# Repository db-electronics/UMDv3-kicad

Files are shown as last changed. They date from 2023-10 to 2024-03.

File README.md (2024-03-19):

# UMDv3
The [Universal Mega Dumper v3](https://github.com/db-electronics/UMDv3) project is an open-source solution for cartridge dumping and writing. 

This PCB includes a very performant MCU, STM32F407VET6, which is connected to a generalized databus consisting of 24 address bits and 16 data lines. Along with a dozen or so control signals, it should be sufficient to interface with most cartridge types. Each cartridge type requires a separate PCB for interface, please refer to the main project repository for a list of currently available cartridge apdapters.

# Project
Please refer to the [UMDv3 Firmware Project Repository](https://github.com/db-electronics/UMDv3) for UMDv3 documentation and instructions; this is the project's central repository and where the wiki is hosted.

# Dependencies
## Parts Libraries
All components in this PCB depend on [my KiCad libraries](https://github.com/db-electronics/kicadlib) which are available here on github. I don't use any pre-existing libraries - *fight me*.

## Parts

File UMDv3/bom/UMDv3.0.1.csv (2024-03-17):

Item | Qty | Reference(s) | Value | Description | Digikey
1 | 14 | C101, C104, C108, C114, C115, C116, C117, C118, C119, C120, C121, C122, C123, C124 | 0.1uF/50V | CAP CER 0.1UF 50V X7R 0603 | 1276-CL10B104KB8NNNLCT-ND
2 | 2 | C102, C103 | 47uF/10V | CAP TANT 47UF 20% 10V 1206 | 478-9009-1-ND
3 | 2 | C105, C106 | 2.2uF/16V | CAP CER 2.2UF 16V X7R 0805 | 399-C0805C225K4RAL7800CT-ND
4 | 4 | C107, C125, C126, C127 | 10uF/25V | CAP CER 10UF 25V X5R 0805 | 1276-2891-1-ND
5 | 2 | C109, C110 | 22pF/50V | CAP CER 22PF 50V C0G/NP0 0603 | 399-6865-1-ND
6 | 3 | C111, C112, C113 | 1uF/16V | CAP CER 1UF 16V X7R 0805 | 399-C0805C105M4RAC7800CT-ND
7 | 1 | CON101 | USB-B1HSB6 | CONN USB TYPE B R/A BLACK | ED2983-ND
8 | 1 | CON104 | JTAG-2X10-HDR | JTAG 2X10 HEADER | ED10524-ND
9 | 1 | CON105 | 101-00405-75 | CONN SD CARD PUSH-PUSH R/A SMD | 101-00405-75-ND
10 | 1 | CON106 | UMDv3-CONN | CONN RCPT 32POS 0.1 GOLD PCB | SAM1211-32-ND
11 | 1 | CON107 | HDR1X3 | CONN HEADER 3 POS 2.54 | 732-5316-ND
12 | 2 | D101, D102 | 151031VS06000 | LED GREEN DIFFUSED 3MM ROUND T/H | 732-5008-ND
13 | 1 | D103 | 151033RS03000 | LED RED CLEAR 3MM ROUND T/H | 732-5013-ND
14 | 1 | FB101 | 1K@100MHz | FERRITE BEAD 1 KOHM 0805 1LN | 732-6704-1-ND
19 | 6 | MEC101, MEC102, MEC103, MEC104, MEC105, MEC106 | NSP-4-6-01 | MACHINE SCREW PAN PHILLIPS 4-40 | RPC3132-ND
20 | 1 | R101 | 1.5k | RES SMD 1.5K OHM 1% 1/10W 0603 | 311-1.5KLDCT-ND
21 | 2 | R102, R103 | 2.2k | RES SMD 2.2K OHM 1% 1/10W 0603 | 311-2.2KLDCT-ND
22 | 4 | R104, R105, R106, R108 | 470 | RES SMD 470 OHM 1% 1/10W 0603 | 311-470LDCT-ND
23 | 2 | R107, R111 | 10k | RES SMD 10K OHM 1% 1/10W 0603 | 311-10KLDCT-ND
24 | 1 | R109 | 715 | RES SMD 715 OHM 1% 1/10W 0603 | 311-715HRCT-ND
25 | 8 | SW101, SW102, SW103, SW104, SW105, SW106, SW107, SW108 | PTS645SM43SMTR92_LFS | SWITCH TACTILE SPST-NO 0.05A 12V | CKN9112CT-ND
26 | 2 | TP101, TP102 | TP_2.25x3_ROUNDED | 0.05" x 0.06" SMT Test Point
27 | 1 | U101 | MCP23008T-E_SS | IC I/O EXPANDER 8BIT I2C 20-SSOP | MCP23008T-E/SSCT-ND
28 | 1 | U102 | AZ1117CH-3.3TRG1 | IC REG LINEAR 3.3V 800MA SOT223 | AZ1117CH-3.3TRG1DICT-ND
29 | 1 | U103 | STM32F407VET6TR | IC MCU 32BIT 512KB FLASH 100LQFP | 497-19657-1-ND
30 | 1 | U104 | SSD1306-0.96-OLED-I2C | 0.96" I2C IIC 128X64 OLED Display Module Arduino Blue Color SSD1306
31 | 1 | X101 | ABLS-8.000MHZ-B4-T | CRYSTAL 8.0000MHZ 18PF SMD | 535-10212-1-ND

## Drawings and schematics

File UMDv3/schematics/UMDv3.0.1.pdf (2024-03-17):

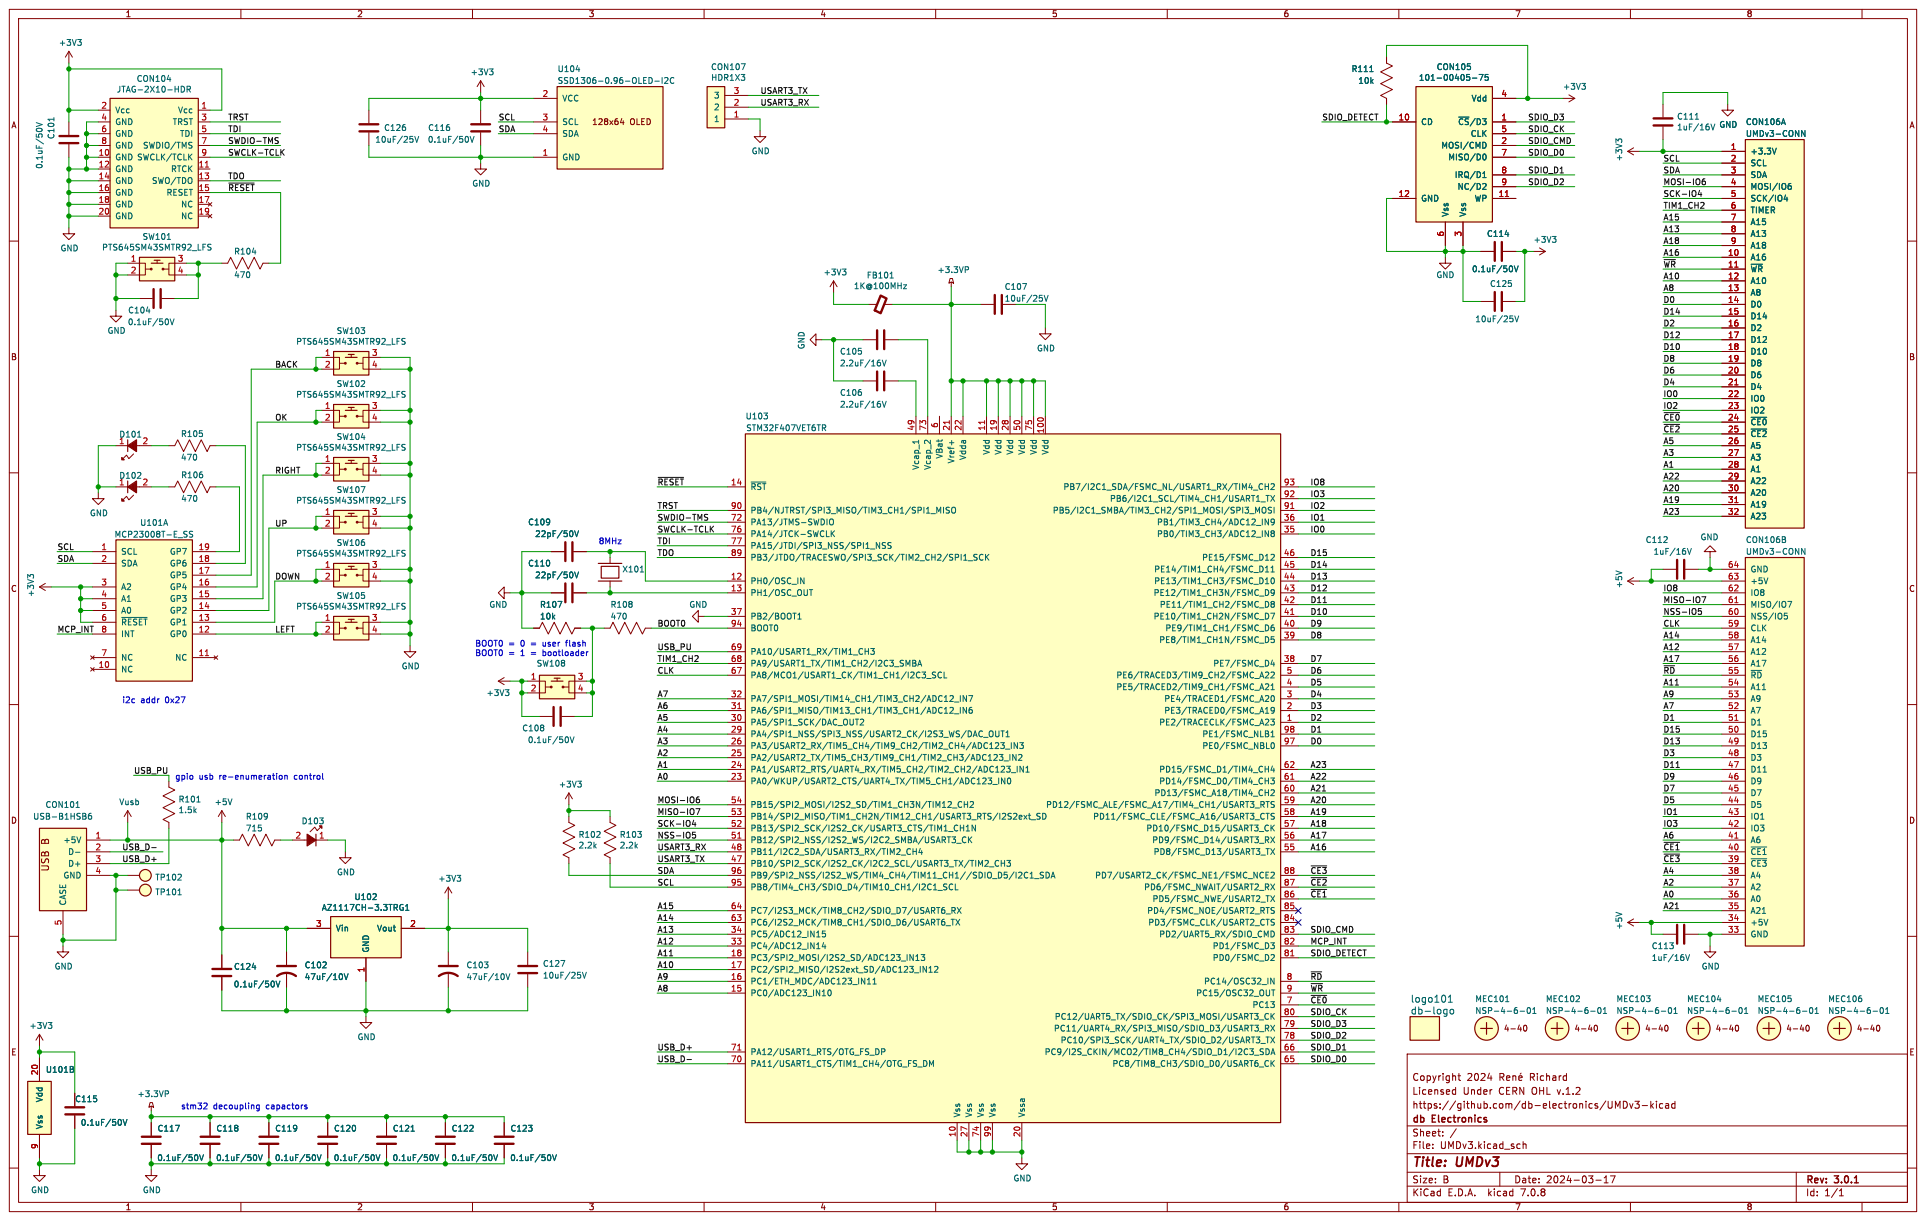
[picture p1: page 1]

A15 A13 TIM1_CH2 A10 ~{WR} A16 A18 A7A9A17 A11 ~{RD} A12 NSS-IO5 A14 CLK D15 D13 D1 SCL SDA

https://github.com/db-electronics/UMDv3-kicad

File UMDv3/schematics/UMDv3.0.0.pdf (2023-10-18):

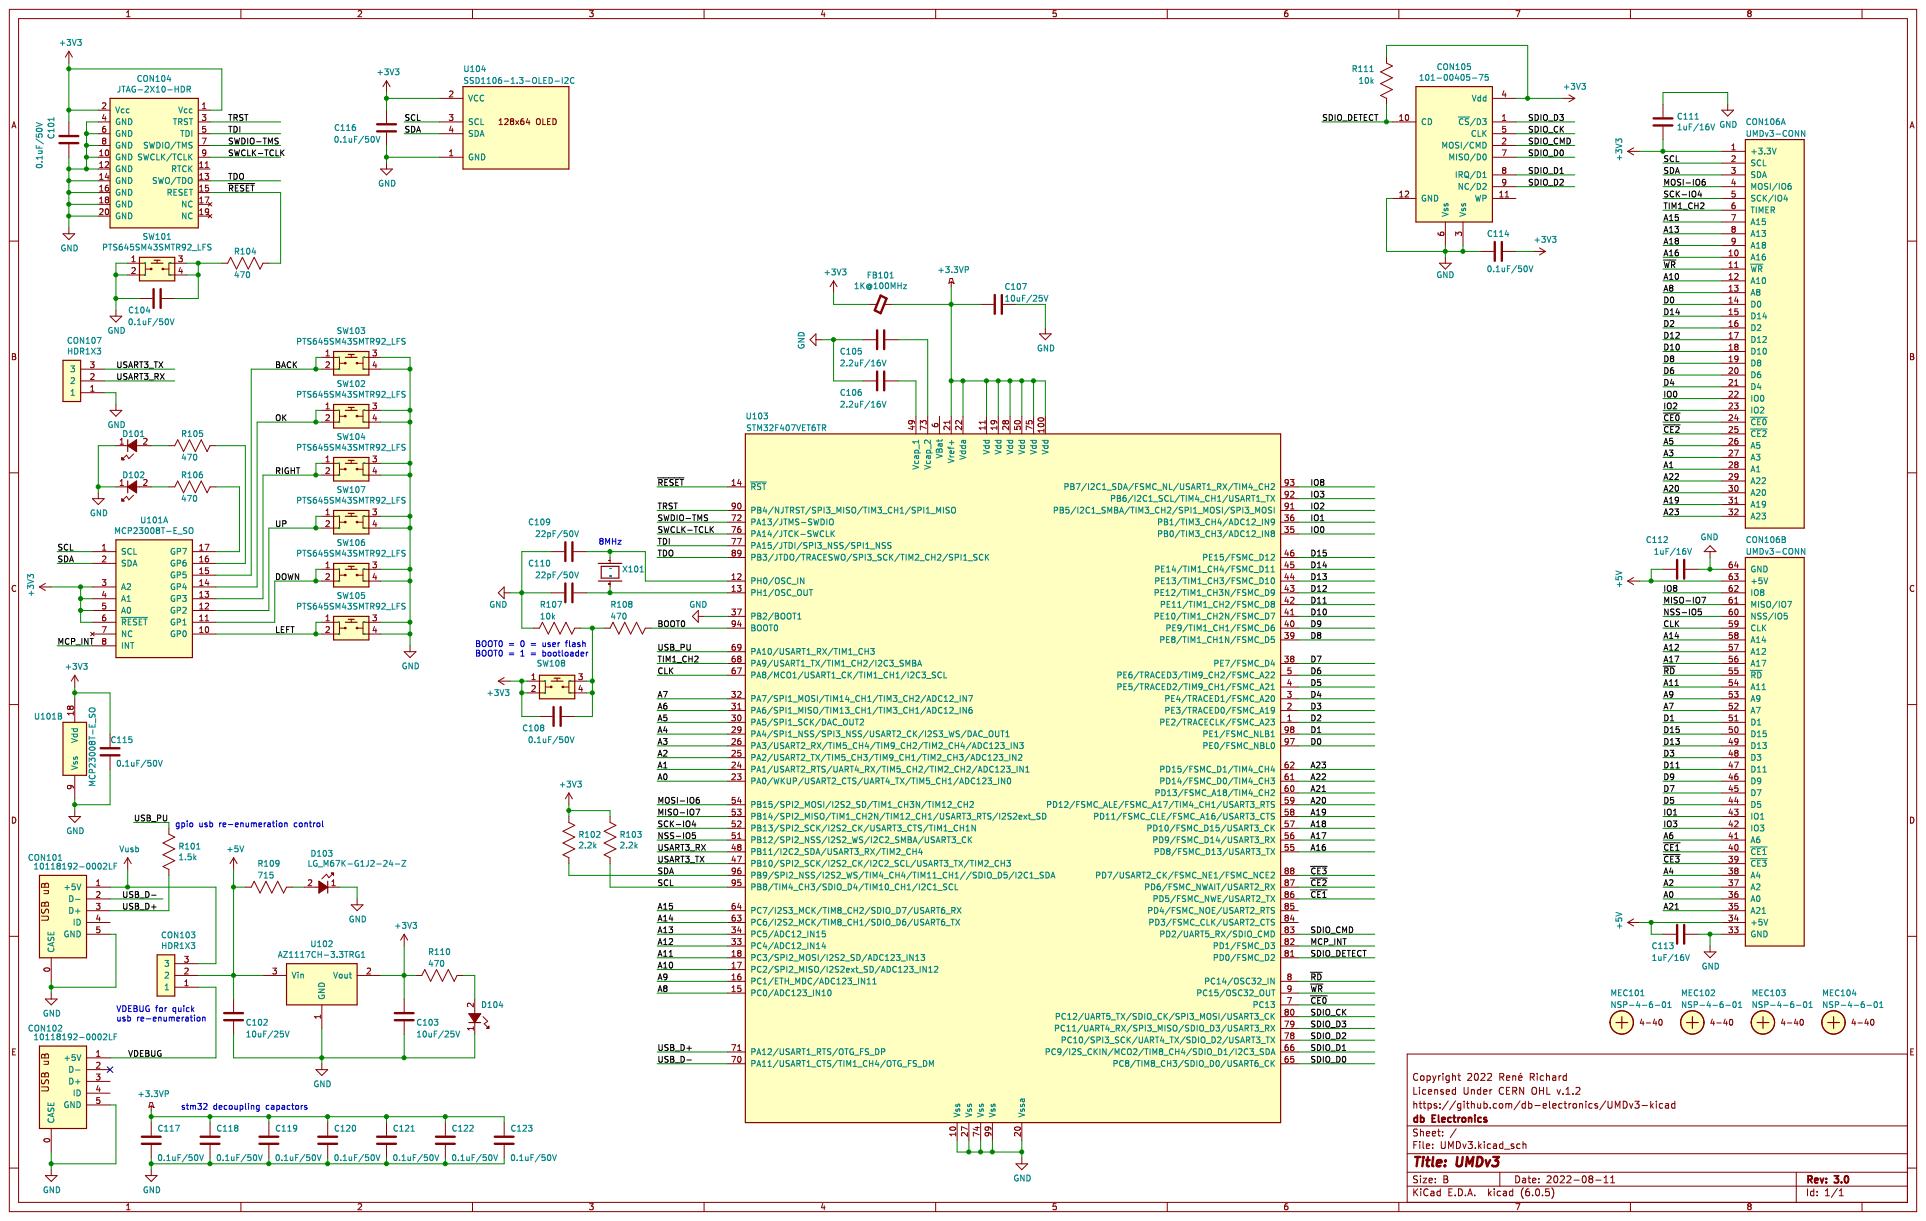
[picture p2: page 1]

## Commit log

2022-01-07 initial files commit
    [UMDv3.kicad_pcb, UMDv3.sch]
2022-01-15 updated gitignore to add schematic and bom to rev control
2022-01-16 building schematic
    [UMDv3.sch]
2022-01-20 added cart connector
    [UMDv3.sch]
2022-01-21 added i2c display
    [UMDv3.kicad_pcb, UMDv3.sch]
2022-01-22 parts placement
    [UMDv3.kicad_pcb, UMDv3.sch]
2022-01-22 more parts placement
    [UMDv3.kicad_pcb, UMDv3.sch]
2022-01-24 routing power to stm32
    [UMDv3.kicad_pcb, UMDv3.sch]
2022-02-05 routing stm32 fanout
    [UMDv3.kicad_pcb]
2022-02-05 more routing
    [UMDv3.kicad_pcb, UMDv3.sch]
2022-02-06 almost done prelim routing
    [UMDv3.kicad_pcb]
2022-02-06 prelim routing almost complete
    [UMDv3.kicad_pcb]
2022-02-10 minor touchups
    [UMDv3.kicad_pcb]
2022-02-12 fixed ground plane connections
    [UMDv3.kicad_pcb]
2022-02-13 improving ground plane coverage
    [UMDv3.kicad_pcb]
2022-08-10 converted project to KiCAD 6.0
    [UMDv3.kicad_pcb, UMDv3.kicad_sch]
2022-08-11 version 3.0 gerbers made
    [UMDv3.kicad_pcb, UMDv3.kicad_sch]
2022-08-23 better file structure
    [UMDv3-B_Cu.gbl, UMDv3-B_Mask.gbs, UMDv3-B_Silkscreen.gbo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]
2023-10-18 updated sch for easier to solder usb conn, no pcb update yet
    [UMDv3.kicad_pcb, UMDv3.kicad_sch]
2023-10-19 changed leds to 3mm, usb conn to th type b
    [UMDv3.kicad_pcb, UMDv3.kicad_sch]
2023-10-21 update to kicad 7
    [UMDv3.kicad_sch]
2024-01-01 more better decoupling capacitance
    [UMDv3.kicad_pcb, UMDv3.kicad_sch]
2024-01-16 improving sd card trace layout
    [UMDv3.kicad_pcb]
2024-03-17 version 3.0.1 files
    [UMDv3.0.1.csv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]
